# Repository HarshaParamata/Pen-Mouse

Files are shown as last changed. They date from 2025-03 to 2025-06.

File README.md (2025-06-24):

#  Pen Mouse – A Wireless Pen-Style Mouse using ATmega328P

The **Pen Mouse** is a compact, pen-like input device that functions similarly to a traditional mouse. It uses an optical sensor to detect movement and buttons for left/right click functionality. Built using affordable and widely available components, this device is ideal for students, designers, and users with limited desk space—particularly during presentations or graphic design work.

---

##  Features

- Move the cursor and perform clicks
- Pen-like ergonomic design for precise control
- Communicates wirelessly via Bluetooth
- Rechargeable and portable

---

##  Components Selection

- **ATmega328P-PU Microcontroller**  
  8-bit AVR RISC-based MCU with DIP-28 package for easy prototyping. Offers sufficient I/O, memory, and Arduino compatibility.

- **HC-06 Bluetooth Module (4-pin)**  
  Provides wireless connectivity. Simple UART interface, works with 3.3V or 5V logic.

- **TPS61023DRLT Switching Regulator**  
  Ensures stable 5V output from a Li-ion battery input, essential for reliable operation.
- **MX8733 Optical Sensor**
   it will track the movement of mouse send to microcontroller.
- **Li-ion Battery**  
  Rechargeable power source for portable use.

- **Arduino Uno**  
  Used for uploading firmware to the ATmega328P.

- **Passive Components (Resistors, Capacitors)**  
  For pull-ups, filtering, and power stabilization.

---
##  Getting Started

###  PCB Design

- The ATmega328P is placed centrally with decoupling capacitors near its power pins.
- SPI lines (MOSI, MISO, SCK, SS) are routed to the HC-06 Bluetooth module via pins 10–13 on the ATmega.
- A voltage regulation circuit using TPS61023DRLT generates a stable 5V from the Li-ion battery.

###  Uploading Code to ATmega328P

1. Use an **Arduino Uno as ISP** to program the ATmega328P.
2. Follow this official Arduino tutorial for setup and connections:  
    [How to program ATmega328P using Arduino Uno – Arduino to Breadboard](https://docs.arduino.cc/built-in-examples/arduino-isp/ArduinoToBreadboard/)
3. Or follow the  [youtude tutorials](https://youtube.com/playlist?list=PLtuqBdbsL-DvbB6QAGgoGBAEsGuXfGFoF&feature=shared).
4. Flash the Pen Mouse firmware (provided in the `codes/` folder).
5. After successful upload, remove the Arduino and power the Pen Mouse from the battery.
####  PINs VIvew of ATmega 328
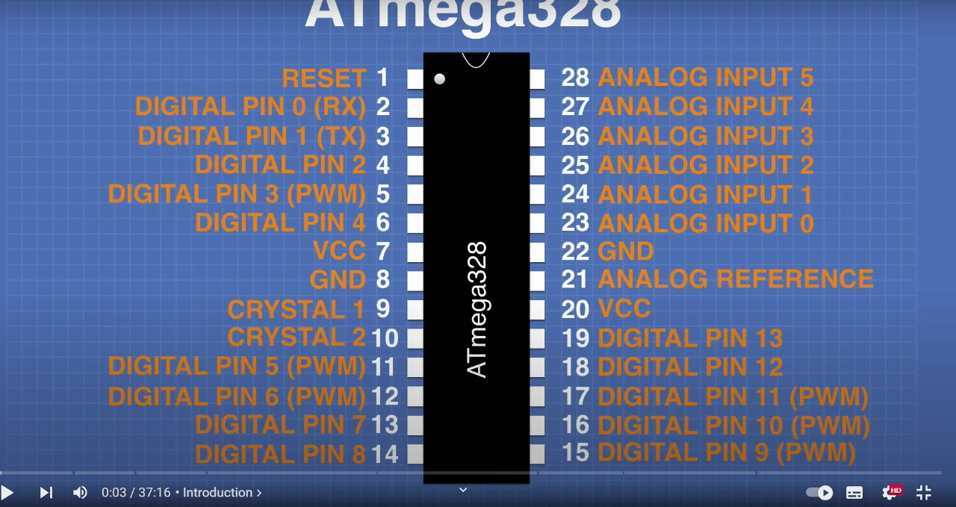
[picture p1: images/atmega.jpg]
AtMega

##  Pen Mouse: Computer-Side Setup Guide (Windows/Linux/macOS)

This guide explains how to configure your computer to receive Pen Mouse input over Bluetooth and convert it into actual mouse movements using a Python script.

---

###  Prerequisites

- Python 3.6 or later
- Pip package manager
- HC-06 Bluetooth module paired with your system
- Basic code/text editor (e.g., Notepad++, VS Code, nano)

---

###  Step 1: Install Required Python Packages

Open your terminal or command prompt and run:

```bash

pip install pyserial pyautogui
```
### Step 2: Create and Save the Python Script

1. Open any code or text editor.
2. Copy the provided Python code for Pen Mouse control (refer to the codes section).
3. Save the file as `pen_mouse.py`.

###  Step 3: Pair HC-06 and Find Serial Port

####  Windows
- Pair HC-06 from **Settings > Devices > Bluetooth**.
- Open **Device Manager > Ports (COM & LPT)** to find the COM port (e.g., `COM5`).

####  Linux

```bash

bluetoothctl

scan on

pair XX:XX:XX:XX:XX:XX

trust XX:XX:XX:XX:XX:XX

connect XX:XX:XX:XX:XX:XX
```
```
ls /dev/rfcomm*
```
####  macOS
- Pair HC-06 via **System Preferences > Bluetooth**.
- Locate the device in Terminal:

```bash

ls /dev/tty.HC-06*
```
###  Step 4: Run the Script

Run the following command in terminal or command prompt:

```bash

python pen_mouse.py
```
Once running, your Pen Mouse should control the system cursor via Bluetooth.

---

###  Permissions and Troubleshooting

### Linux/macOS Serial Port Permissions

```bash

sudo chmod a+rw /dev/rfcomm0          # Linux

sudo chmod a+rw /dev/tty.HC-06-DevB   # macOS
```

####  macOS Accessibility Permissions

- Go to **System Preferences > Security & Privacy > Accessibility**
- Add and allow your Terminal or Python environment to control your mouse
###  References

- [PySerial Documentation](https://pyserial.readthedocs.io/)
- [PyAutoGUI Documentation](https://pyautogui.readthedocs.io/)

---

##  Hardware Snapshots

###  Schematic Diagram  
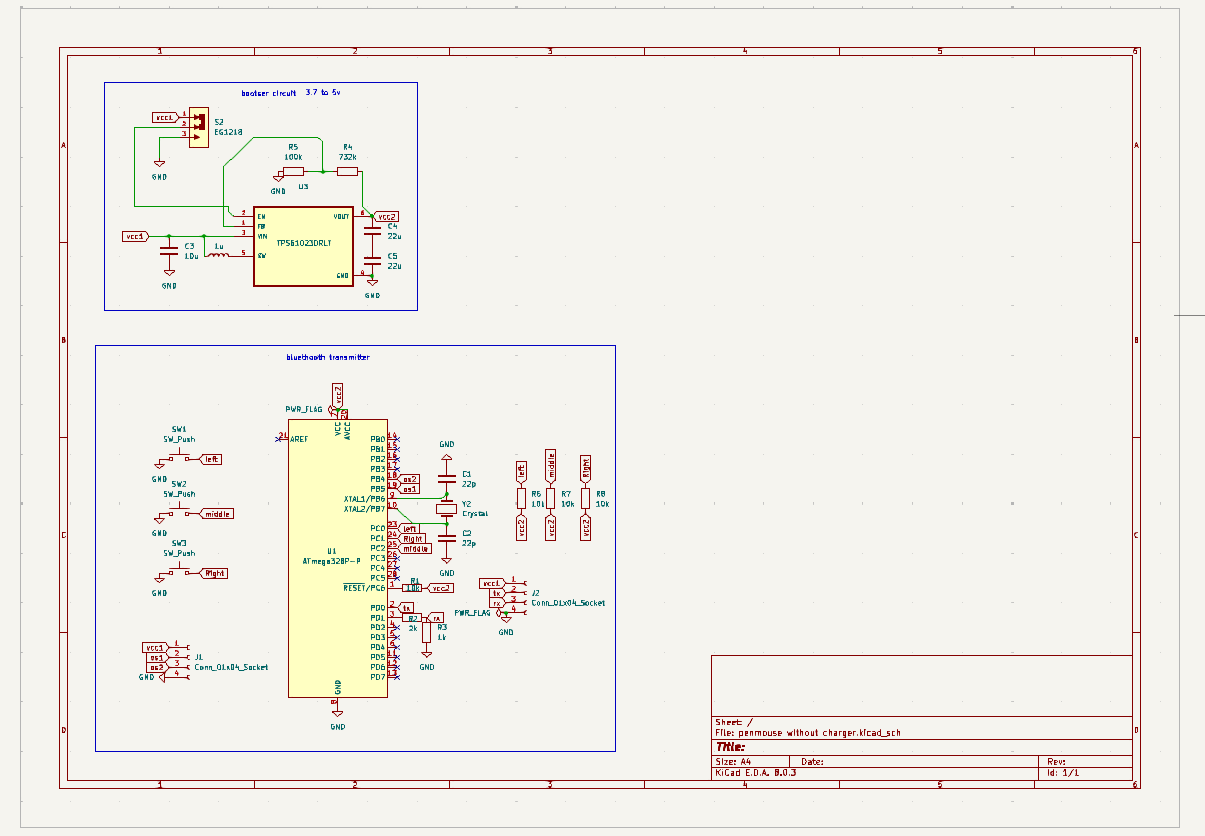
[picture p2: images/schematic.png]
Schematic


###  PCB Layout  
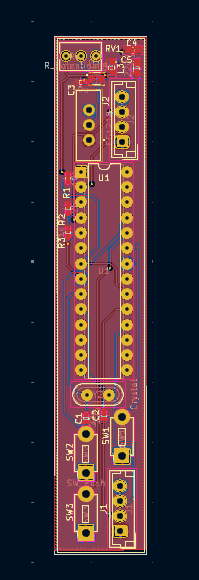
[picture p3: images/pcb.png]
PCB


###  3D PCB View  
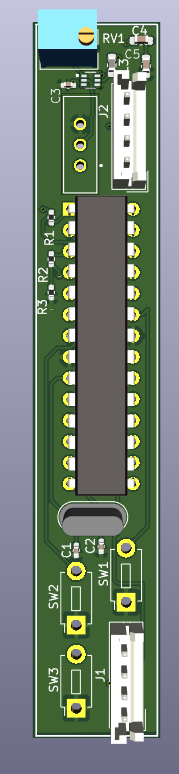
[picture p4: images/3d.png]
3D

---

##  Repository Structure
```
PenMouse/  

├── kicad files/ # Schematic,BOM and PCB file 

├── images/ # Schematic and PCB images

├── datasheets/ # datasheet of components used

├── codes/ # code used for promgraming atmega and computer

├── Introduction # introduction and first idea of the project

├── PCB design # pcb design review

└── README.md

```
---

##  Future Improvements

- Add rechargeable support with USB charging
- Integrate gesture detection
- Replace HC-06 with BLE module for lower power and broader compatibility

---
## Team Members
 1. Kurre Vinay - EE23BTECH11036
 2. P.Harsha Vardan Kumar - EE23BTECH11214
 3. K S Ballavardhan - EE23BTECH11209
 4. Kailash C - EE23BTECH11207
 5. Manoj Kumar - EE23BTECH11211 

##  License

This project is licensed under the MIT License. See `LICENSE` file for details.

---

##  Contributing

Pull requests are welcome! For major changes, please open an issue first to discuss what you'd like to change.

---

##  Acknowledgements

- Inspired by DIY input devices and custom hardware projects
- Built at **IIT Hyderabad** as part of a ESDP Course Project

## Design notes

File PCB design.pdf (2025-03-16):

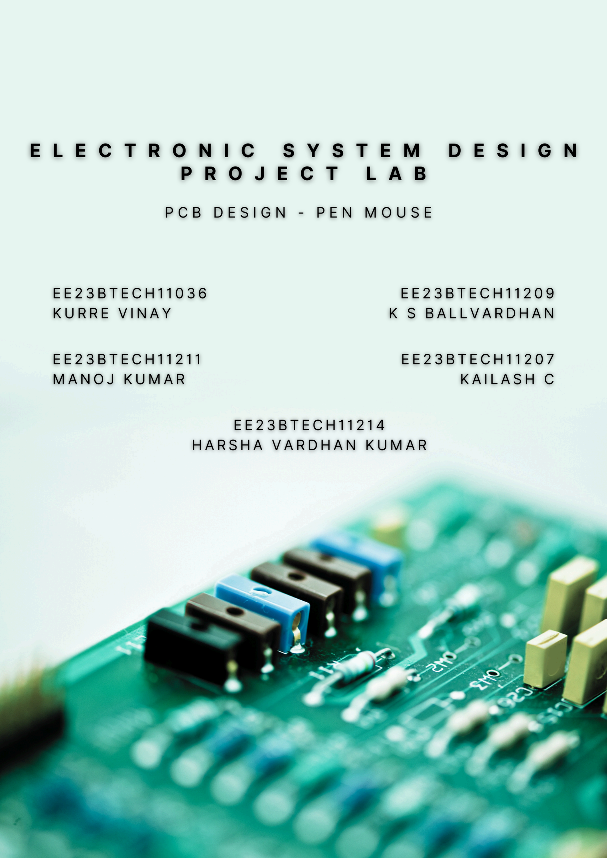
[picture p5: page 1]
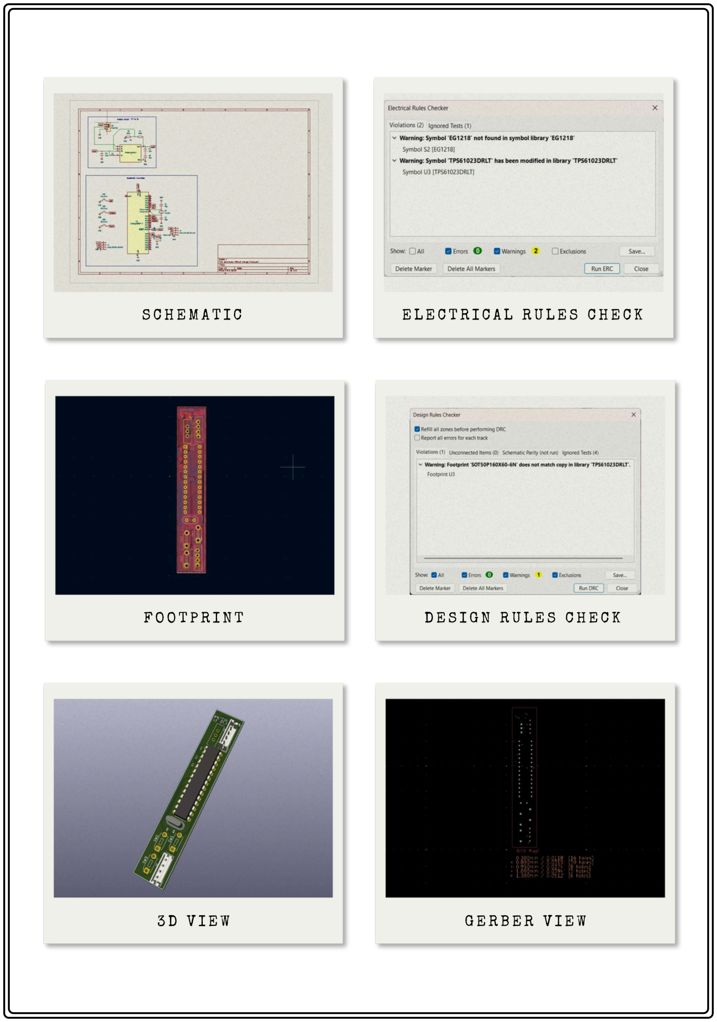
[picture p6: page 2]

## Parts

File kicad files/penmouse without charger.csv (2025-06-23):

'Reference' | 'Value' | 'Datasheet' | 'Footprint' | 'Qty' | 'DNP'
'C1,C2' | '22p' | '~' | 'Capacitor_SMD:C_0402_1005Metric' | '2' | ''
'C3' | '10u' | '~' | 'Capacitor_SMD:C_0402_1005Metric' | '1' | ''
'C4,C5' | '22u' | '~' | 'Capacitor_SMD:C_0402_1005Metric' | '2' | ''
'J1,J2' | 'Conn_01x04_Socket' | '~' | 'Connector_JST:JST_EH_B4B-EH-A_1x04_P2.50mm_Vertical' | '2' | ''
'L3' | '1u' | '~' | 'Inductor_SMD:L_0402_1005Metric' | '1' | ''
'R1,R6,R7,R8' | '10k' | '~' | '-- mixed values --' | '4' | ''
'R2' | '2k' | '~' | 'Resistor_SMD:R_0402_1005Metric' | '1' | ''
'R3' | '1k' | '~' | 'Resistor_SMD:R_0402_1005Metric' | '1' | ''
'R4' | '732k' | '~' | 'Resistor_SMD:R_0402_1005Metric' | '1' | ''
'R5' | '100k' | '~' | 'Resistor_SMD:R_0402_1005Metric' | '1' | ''
'S2' | 'EG1218' | '' | 'EG1218:SW_EG1218' | '1' | ''
'SW1,SW2,SW3' | 'SW_Push' | '~' | 'Button_Switch_THT:SW_PUSH_1P1T_6x3.5mm_H4.3_APEM_MJTP1243' | '3' | ''
'U1' | 'ATmega328P-P' | 'http://ww1.microchip.com/downloads/en/DeviceDoc/ATmega328_P%20AVR%20MCU%20with%20picoPower%20Technology%20Data%20Sheet%2040001984A.pdf' | 'Package_DIP:DIP-28_W7.62mm' | '1' | ''
'U3' | 'TPS61023DRLT' | '' | 'TPS61023DRLT:SOT50P160X60-6N' | '1' | ''
'Y2' | 'Crystal' | '~' | 'Crystal:Crystal_HC52-8mm_Vertical' | '1' | ''

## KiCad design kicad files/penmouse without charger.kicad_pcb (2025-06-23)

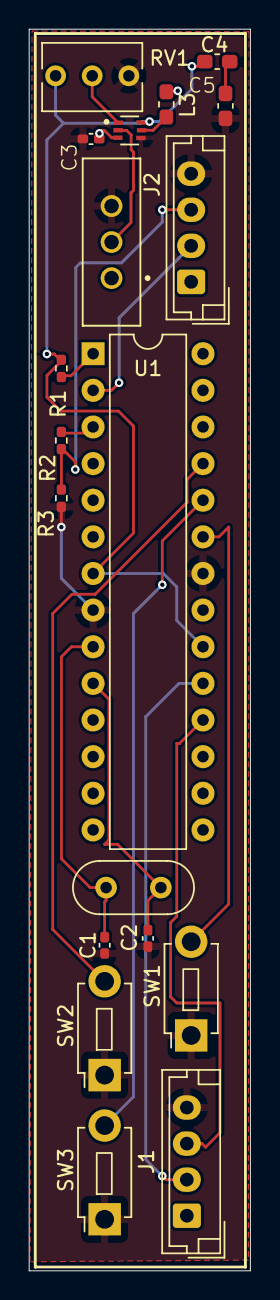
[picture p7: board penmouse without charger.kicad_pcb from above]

Board: 2 copper layers, 15.3 x 86.1 mm, 19 parts (0 on the bottom side), 18 nets.

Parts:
C1, C2: 22p; C_0402_1005Metric_Pad0.74x0.62mm_HandSolder
C3: 10u; C_0402_1005Metric_Pad0.74x0.62mm_HandSolder
C4, C5: 22u; C_0603_1608Metric_Pad1.08x0.95mm_HandSolder
J1, J2: Conn_01x04_Socket; JST_EH_B4B-EH-A_1x04_P2.50mm_Vertical
L3: 1u; L_0603_1608Metric_Pad1.05x0.95mm_HandSolder
R1: 10k; R_0402_1005Metric_Pad0.72x0.64mm_HandSolder
R2: 2k; R_0402_1005Metric_Pad0.72x0.64mm_HandSolder
R3: 1k; R_0402_1005Metric_Pad0.72x0.64mm_HandSolder
RV1: R_Potentiometer; Potentiometer_Bourns_3266Y_Vertical
S2: EG1218; SW_EG1218
SW1, SW2, SW3: SW_Push; SW_PUSH_1P1T_6x3.5mm_H4.3_APEM_MJTP1243
U1: ATmega328P-P; DIP-28_W7.62mm
U3: TPS61023DRLT; SOT50P160X60-6N
Y2: Crystal; Crystal_HC52-8mm_Vertical

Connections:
GND: C1.1, C2.2, C3.1, C5.2, J1.4, J2.4, R3.2, RV1.1, S2.3, SW1.1, SW2.1, SW3.1, U1.8 (GND), U1.22 (GND), U3.4 (GND)
unnamed: C4.2, C5.1
unnamed: R2.2, U1.3 (PD1)
unnamed: C1.2, U1.9 (XTAL1/PB6), Y2.2
unnamed: C2.1, U1.10 (XTAL2/PB7), Y2.1
unnamed: R1.1, U1.1 (~RESET/PC6)
unnamed: S2.2, U3.2 (EN)
unnamed: RV1.2, U3.1 (FB)
unnamed: L3.2, U3.5 (SW)
Right: SW3.2, U1.24 (PC1)
left: SW1.2, U1.23 (PC0)
middle: SW2.2, U1.25 (PC2)
os1: J1.2, U1.19 (PB5)
os2: J1.3, U1.18 (PB4)
rx: J2.3, R2.1, R3.1
tx: J2.2, U1.2 (PD0)
vcc1: C3.2, J1.1, J2.1, L3.1, S2.1, U3.3 (VIN)
vcc2: C4.1, R1.2, RV1.3, U1.7 (VCC), U1.20 (AVCC), U3.6 (VOUT)

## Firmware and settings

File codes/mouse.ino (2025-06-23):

#include <avr/io.h>
#include <util/delay.h>
#include <avr/interrupt.h>

#define F_CPU 16000000UL
#define BAUD_RATE 9600

// Define pins for buttons
#define LEFT_CLICK_PIN PC0
#define RIGHT_CLICK_PIN PC1

// Define MX8733B sensor pins
#define SENSOR_SCLK PB5
#define SENSOR_SDIO PB4
#define SENSOR_NCS PB3

// UART initialization
void UART_init(void) {
    uint16_t ubrr = F_CPU/16/BAUD_RATE - 1;
    UBRR0H = (unsigned char)(ubrr>>8);
    UBRR0L = (unsigned char)ubrr;
    UCSR0B = (1<<RXEN0)|(1<<TXEN0);
    UCSR0C = (1<<UCSZ01) | (1<<UCSZ00);
}

void UART_transmit(unsigned char data) {
    while (!(UCSR0A & (1<<UDRE0)));
    UDR0 = data;
}

// SPI functions for MX8733B
void SPI_init() {
    DDRB |= (1<<SENSOR_SCLK)|(1<<SENSOR_NCS);
    DDRB &= ~(1<<SENSOR_SDIO);
    PORTB |= (1<<SENSOR_NCS);
}

uint8_t SPI_transfer(uint8_t data) {
    uint8_t i;
    for (i = 0; i < 8; i++) {
        if (data & 0x80)
            PORTB |= (1<<SENSOR_SDIO);
        else
            PORTB &= ~(1<<SENSOR_SDIO);
        
        PORTB |= (1<<SENSOR_SCLK);
        _delay_us(1);
        data <<= 1;
        if (PINB & (1<<SENSOR_SDIO))
            data |= 1;
        PORTB &= ~(1<<SENSOR_SCLK);
        _delay_us(1);
    }
    return data;
}

void MX8733B_write(uint8_t address, uint8_t data) {
    PORTB &= ~(1<<SENSOR_NCS);
    SPI_transfer(address | 0x80);
    SPI_transfer(data);
    PORTB |= (1<<SENSOR_NCS);
}

uint8_t MX8733B_read(uint8_t address) {
    PORTB &= ~(1<<SENSOR_NCS);
    SPI_transfer(address);
    uint8_t data = SPI_transfer(0x00);
    PORTB |= (1<<SENSOR_NCS);
    return data;
}

void MX8733B_init() {
    _delay_ms(50);  // Power-up delay
    MX8733B_write(0x0D, 0x01);  // Enter configuration mode
    _delay_ms(1);
    MX8733B_write(0x0E, 0x80);  // Reset
    _delay_ms(1);
    MX8733B_write(0x0D, 0x00);  // Exit configuration mode
    _delay_ms(1);
}

int main(void) {
    UART_init();
    SPI_init();
    MX8733B_init();

    DDRC &= ~((1<<LEFT_CLICK_PIN)|(1<<RIGHT_CLICK_PIN));
    PORTC |= (1<<LEFT_CLICK_PIN)|(1<<RIGHT_CLICK_PIN);

    int8_t dx, dy;
    uint8_t buttons;

    while(1) {
        buttons = 0;
        if (!(PINC & (1<<LEFT_CLICK_PIN))) buttons |= 0x01;
        if (!(PINC & (1<<RIGHT_CLICK_PIN))) buttons |= 0x02;

        uint8_t motion = MX8733B_read(0x02);
        if (motion & 0x80) {
            dx = MX8733B_read(0x03);
            dy = MX8733B_read(0x04);
        } else {
            dx = dy = 0;
        }

        UART_transmit(buttons);
        UART_transmit(dx);
        UART_transmit(dy);

        _delay_ms(10);
    }

    return 0;
}

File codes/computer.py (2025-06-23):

import serial
import pyautogui
import time

# Replace with your HC-06 COM port
SERIAL_PORT = 'COM5'
BAUD_RATE = 9600

try:
    ser = serial.Serial(SERIAL_PORT, BAUD_RATE, timeout=1)
    print(f"Connected to {SERIAL_PORT} at {BAUD_RATE} baud.")
    time.sleep(2)  # Allow Bluetooth to stabilize
except:
    print(f"Failed to connect to {SERIAL_PORT}.")
    exit()

# Main loop
while True:
    if ser.in_waiting >= 3:
        data = ser.read(3)
        buttons = data[0]
        dx = data[1] - 256 if data[1] > 127 else data[1]
        dy = data[2] - 256 if data[2] > 127 else data[2]

        # Move mouse (invert Y to match natural direction)
        pyautogui.moveRel(dx, -dy)

        # Handle mouse clicks
        if buttons & 0x01:
            pyautogui.mouseDown(button='left')
        else:
            pyautogui.mouseUp(button='left')

        if buttons & 0x02:
            pyautogui.mouseDown(button='right')
        else:
            pyautogui.mouseUp(button='right')

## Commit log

2025-03-16 Add files via upload
    This repository update includes KiCad designs, an updated Bill of Materials (BOM), and comprehensive reports. Key files include:
    Schematic (.kicad_sch) and PCB layout (.kicad_pcb) for circuit design.
    Drill files (.drl) for PCB fabrication.
    Updated BOM with component details.
    Reports summarizing design decisions and outcomes.
    PDF Documentation for quick reference.
    [penmouse without charger.csv, penmouse.kicad_pcb, penmouse.kicad_sch]
2025-03-16 Delete Bill of Materials.xlsx
    Bill of materials has been removed to ensure accuracy and alignment with the updated component list.
    [Bill of Materials.xlsx]
